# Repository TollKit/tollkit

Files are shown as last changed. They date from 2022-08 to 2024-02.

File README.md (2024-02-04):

# Sistema de Control de Acceso por COVID-19

             ![]() ![]() ![]() ![]() ![]() ![]() ![]() 

 <a width="400" href='https://postimages.org/' target='_blank'>Toll-Kit-github</a>

## Acerca del Proyecto

<a href='https://postimg.cc/GTtQ7r0N' target='_blank'>Whats-App-Image-2022-09-27-at-5-39-10-PM</a>

### Demo

https://drive.google.com/file/d/1ykN8uWTC-Xn_GCya3o3VD92Z7eDFktyV/view?usp=sharing

### Motivación

Buscamos inspirar a la próxima generación de científicxs e ingenierxs para que nos ayuden a explorar y aprender sobre tecnología. Compartimos la documentación completa de este dispositivo como una forma de aporte al desarrollo tecnológico a través de un proyecto divertido.

### Habilidades

Este proyecto tiene elementos de ensamblaje mecánico, utiliza componentes electrónicos y tiene un software que se encargará de ejecturar todo. Para completar con éxito este proyecto necesitará tener algo de experiencia en lo siguiente:

* **Diseño Mécanico:** Para diseñar el chasis junto a los compartimentos para almacenar cada módulo electrónico.

* **Electrónica:** Para implementar los diferentes módulos electrónicos que luego serán comunicados por MQTT a Flask.

* **Software:** Para el reconocimiento de mascarilla, detección del carnet de vacunación a través del QR y el desarrollo web.

La mayoría de requisitos son habilidades que puede aprender y adquirir con bastante rapidez viendo videos e investigando en Internet, y a lo largo del proyecto también tratamos de brindar información complementaria sobre algunas de ellas.

### Compromiso de tiempo esperado

Según nuestra experiencia, la construcción de este proyecto requiere no menos de 100 horas-persona y, según la familiaridad y el nivel de habilidad de los involucrados, podría ser mucho más. *Sin embargo, este proyecto principalmente pretende ser una herramienta de enseñanza y aprendizaje.* A lo largo de la documentación, tratamos de brindar información complementaria para aquellos que puedan ser nuevos en este tipo de proyecto.

### Roadmap de implementación

<a href='https://postimg.cc/MMtP3vhz' target='_blank'>roadmap-Toll-Kit</a>

Esta es una ruta para construir un TollKit y se divide en 6 etapas:

* **Etapa 1:** Empieza planificando el proyecto, teniendo en cuenta la disponibilidad de cada miembro, conocimientos y nuevas funcionalidades que quieran integrarle. Te recomendamos usar Trello!

* **Etapa 2:** Consigue todos los componentes electrónicos, filamento y elabora una arquitectura de software.
* **Etapa 3:** Empieza a probar el correcto funcionamiento de cada módulo electrónico por separado y descarga las librerías/frameworks necesarios.
* **Etapa 4:** Ensambla el diseño 3D y prueba los módulos de visión computarizada.
* **Etapa 5:** Monta los módulos electrónicos en el chasis e integralos con el servidor de Flask.
* **Etapa 6:** Después de que todo haya sido probado, calibrado y el software esté funcionando, ¡TollKit estará listo para su uso!

## Empieza aquí

* [Propósito](https://github.com/TollKit/tollkit/blob/master/proposito.md)

* [Electrónica](https://github.com/TollKit/tollkit/blob/master/electronic_device/docElectronica.md)
* Visión Computarizada
    * [Reconocimiento de Mascarilla](https://github.com/TollKit/tollkit/blob/master/web_app/server/flask_app/faceMask_detection/docDeteccionMascarilla.md)
    * [Detección del Carnet de Vacunación](https://github.com/TollKit/tollkit/blob/master/web_app/server/flask_app/QRcard_vacunation/docCarnetVacunacion.md)
* [Diseño 3D](https://github.com/TollKit/tollkit/blob/master/diseno_3D/docDiseno3D.md)
* [Desarrollo Web](https://github.com/TollKit/tollkit/blob/master/web_app/server/docDesarrolloWeb.md)

## Equipo

Estos fueron los creadores originales de este proyecto. Ahora, este repositorio open source está a la disposición de la comunidad tecnológica.

(https://postimg.cc/Bj5rPLWx)

<ul>
    <li>[Sebastian Nizama](https://www.linkedin.com/in/sebastian-nizama/) Sebastián Nizama (Electrónica) </li>
    <li>[Richard Elescano](https://www.linkedin.com/in/richard-elescano-reyna-9a6311224/) (Electrónica) </li>
    <li>[Marko Julca](https://www.linkedin.com/in/markostephano/) (Visión Computarizada & Diseño 3D) </li>
    <li>[Nicolas Silva](https://www.linkedin.com/in/nicolas-silva-matute/) (Electrónica & Diseño 3D) </li>
    <li>[Jhomar Astuyauri](https://www.linkedin.com/in/jhomar-astuyauri/) (Producto & Desarrollo de Software) </li>
</ul>

### Especial agradecimiento

Héctor Llamaccponca, Jean Kevin Inga y Paulo Quispe

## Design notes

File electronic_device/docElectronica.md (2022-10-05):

<h1>Desarrollo Electrónico</h1>

<h2>Componentes electrónicos</h2>

| Componente  | Descripción  | Imágen de referencia |
| :--- |:---| -----:|
| RFID módulo RC522 | El módulo RC522 es Lector-Grabador RFID 13.56MHz, posee comunicación SPI lo que permite trabajar fácilmente con la mayoría de microcontroladores. El rango de detección de tags RFID es de aprox. 5-7cm. Compatible con Arduino, Pic, Raspberry Pi y más. | <a href='https://postimg.cc/D8qqJHrj' target='_blank'>RFID</a> |
| Sensor ultrasónico HC-SR04  | Es un módulo electrónico que incorpora un par de transductores de ultrasonido que se utilizan de manera conjunta para determinar la distancia entre el sensor (módulo) y un objeto. El tiempo entre la transmisión y la recepción de la señal ultrasónica es usada para calcular la distancia.  |  <a href='https://postimg.cc/V0LczT44' target='_blank'>pngwing-com</a>|
| Sensor de temperatura infrorrojo Mlx90614 | Es un chip de silicio con una fina membrana micro mecanizada,diseñada para ser sensible a la radiación infrarroja emitida por un objeto a distancia. El sensor posee internamente una etapa de amplificación y digitalización(ADC) de la señal procedente de la membrana. La salida del sensor es lineal y se compensa de acuerdo a las variaciones de la temperatura ambiente. | <a href='https://postimg.cc/hfD9qrnj' target='_blank'>MLX90614</a> |
| Relé optoacoplador de 5 V | Este módulo relé sirve para conmutación de cargas de potencia. Los contactos de los relevadores están diseñados para conmutar cargas de hasta 10 A y 250VAC (30VDC), aunque se recomienda dejar un margen abajo de estos límites. El modulo permite manejar la bobina del relé y la señal de control puede provenir de cualquier circuito de control TTL como un microcontrolador o tarjeta Arduino salidas desde 3.3V-5V. |  <a href='https://postimg.cc/DWY6xpF1' target='_blank'>rele</a>|
| Bomba de agua AD20P | Es una bomba de agua DC sin escobillas con las características de larga vida, bajo ruido, chispa inversa, etc. Sin interferencias electromagnéticas. Voltaje de funcionamiento: CC 12 V. Corriente de funcionamiento: 400 mA. Cabezal máximo: 118.1 in. Caudal máximo: 240 L.  |  <a href='https://postimg.cc/7fYVyy6S' target='_blank'>pump</a>|
| ESP32 | Microcontrolador programable con ide arduino con un módulo WiFi integrado. Este será usado para la adquisición de las señales porvenientes de los sensores y del envío de datos mediante MQTT.  |  <a href='https://postimg.cc/dDX7BYmQ' target='_blank'>esp32</a>|

<h2>Implementación</h2>
<h3>Sensor de temperatura</h3>
Para esta aplicacion en especifico se uso este sensor para medir la temperatura corporal de las personas que desean ingresar a un espacio publico y que segun bajo las regulaciones del minsa ésta no puede exceder los 38°C.
<a href='https://postimg.cc/0r5stBmr' target='_blank'>MLX90614-with-ESP32-connection-diagram</a>

---------

Las conexiones serán las siguientes:

* VIN: +3.3V - +5.0V DC
* GND: 0V Tierra
* SCL: I2C clock
* SCL: I2C clock
* SDA: I2C data

---------
Para usar este sensor en el IDE de arduino debemos descargar la librería "Adafruit_MLX90614.h"

--------

Inicialmente llamamos a las librerias a utilizar , luego definimos las variables alarma y calibracion que seran las necesarias para indicar cuando la temperatura corporal de la persona sobrepase los 38°C, y la variable calibracion es necesaria para obtener una medicion mas exacta de nuestro sensor. Luego en el programa utilizamos el metodo de la clase mlx , el cual es :"mlx.readObjectTempC" el cual nos brindara la temperatura en °C, con este valor ajustaremos el valor de alarma para que envie un mensaje cuando se sobrepase el valor maximo. Finalmente enviaremos los datos via wifi utilizando el ESP32 con la libreria pubsubclient y mediante el protocolo MQTT.

<h3>Sensor ultrasónico</h3>
Para esta aplicación en específico se usó este sensor para realizar un dispensador en gel sin contacto, es decir, las personas en el ingreso al establecimiento solo deben acercar sus manos cierta distancia y con ayuda de este sensor se activará una bomba para dispensar alcohol en gel a fin de desinfectar las manos de la persona y cumplir con los protocolos sanitarios.
<a href='https://postimg.cc/8jJLqDrC' target='_blank'>1617136789-426-Tutorial-de-sensores-ultrasonicos-para-Arduino-ESP8266-y-ESP32</a>

---------

Las conexiones serán las siguientes:

* VCC (+5V DC)
* TRIG (Disparo del ultrasonido)
* ECHO (Recepción del ultrasonido)
* GND (Tierra: 0V)

---------
Para usar este sensor en el IDE de arduino no se utiliza librerías especiales para el sensor, solamente se utiliza la función "pulseIn" incluida en el IDE de Arduino para medir la longitud del pulso de eco que devuelve el sensor ultrasónico.

--------

Inicialmente se definen las variables en los pines y su estado de entrada o salida En este caso en particular se utilizó un relé como salida para activar la bomba que nos dispensara el alcohol en gel. Luego en el programa se realiza la ecuación del tiempo con la funcion Pulsein y se configura par aunque si la distancia es menor a 5 el relé se active y de lo contrario no lo haga Finalmente enviaremos los datos que indiquen si el relé se activó o no via wifi utilizando el ESP32 con la libreria "wifi.h" y la libreria "pubsubclient" para usar el protocolo MQTT.

<h3>Módulo RFID</h3>
Para esta aplicacion en especifico se uso este modulo para regular el ingreso en los establecimientos solo de personas autorizadas pertenecientes a la organizacion o invitados registrados.

<a href='https://postimg.cc/9RyyrBCq' target='_blank'>RFID-ESP32-Node-MCU-Steckplatine</a>

---------

Las conexiones serán las siguientes:

<a href='https://postimg.cc/ThqHsVgw' target='_blank'>nfc-osc-bb-g-Bdc-Dg8-Rq9</a>

---------
Para poder trabajar el Modulo en Arduino es necesario descargar su librería correspondiente, la que usaremos será la libreria : "MFRC522"

--------

Se tiene primero un código para leer el código de identificación de nuestros Tags, lo cual es necesario para realizar el control de acceso. Una vez obtenido los códigos de nuestros tags, ya podemos realizar el control de acceso indicando que códigos serán los que tendrán permitidos el ingreso, para ello primero se llama a las librerias a utilizar y luego de esto se crea objeto mfrc522 enviando pines de slave select y reset con esta linea: 
* MFRC522 mfrc522(SS_PIN, RST_PIN);
Posterior a esto se definen los usuarios que tendran permitido el ingreso, en este caso son los siguientes:
* byte Usuario1[4]= {0x82, 0x95, 0x40, 0x1C} ;    // UID de tarjeta leido en programa 1
* byte Usuario2[4]= {0xE0, 0xB2, 0x4E, 0xD3} ;    // UID de llavero leido en programa 1
Luego, con los metodos 
* mfrc522.PICC_IsNewCardPresent y mfrc522.PICC_ReadCardSerial
conoceremos si hay una tarjeta presente o si no se peuden obtener datos 
de la tarjeta
finalmente se imprime el mensaje de acceso concedido o acceso denegado
Todos los datos son enviados via WiFi por el ESP 32 con la libreria "WiFi.h"
y "pubsubclient" para hacer uso del protocolo MQTT

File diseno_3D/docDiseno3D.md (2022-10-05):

<h1>Desarrollo del Diseño 3D </h1>

Para el diseño 3D se utilizaron diferentes formas:

* Pirámide de 585 mm con base de 100 mm x 100 mm, de este se cortó 150 mm de altura con un cubo hueco.

* Para la superficie se utilizaron cuñas, que son formas de triangulo rectangulo que permiten hacer lineas sobresalientes.

* Para la salida donde se coloca la cámara, tendrems cilindros huecos y un circulo que genere una base que sobresalga. Se hicieron agujeros con los cilindros de 10 mm de diámetro.

* Para el RFID se utilizó un prisma rectangular con un hueco hecho usando un óvalo de 70 mm x 40 mm.

* Este prisma se inclinó para que sea de fácil acceso y se incrustó a TOLLKIT usando otro prisma de 60 mm x 40 mm.

* En la tapa se unieron dos prismas rectangulares, uno de 94 mm x 156 mm y otro de 90 mm x 50 mm. Estos se conectan con otro prisma de 30 mm x 94 mm.

* Finalmente, se realizaron huecos en la tapa usando formas vacias para que sea de fácil apertura.

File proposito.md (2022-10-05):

A día de hoy la pandemia ha cambiado en muchas formas la manera en cómo salimos y entramos a establecimientos (Centros comerciales, restaurantes, universidades, etc.) por restricciones de COVID-19. A partir de esto han surgido nuevas responsabilidades como el del personal de seguridad encargado de verificar si cuentas con Mascarilla, Carnet de Vacunación con 3 dosis, Temperatura menor a 38.5, Carnet Universitario, verter alcohol en gel para la desinfección de tus manos y finalmente permitirte el pase al establecimiento.
<p>Identificamos las siguientes 3 problemáticas:</p>
<ul>
    <li>Realizar este tipo de tareas repetitivas termina siendo estresante para el personal de seguridad generando tensiones musculares, inflamación, problemas con los nervios, etc.</li>
    <li>Al ser el personal de seguridad un intermediario entre todas las personas del exterior y el establecimiento, existe un mayor riesgo de contagio debido a que si el personal de seguridad se contagia de forma asintomática, podría inconscientemente contagiar a cada persona que va ingresando al establecimiento siendo esto perjudicial.</li>
    <li>Es cierto que en muchos lugares el personal de seguridad está atento a que cada persona cumpla con las consideraciones mínimas para ingresar a un establecimiento, sin embargo, también es cierto que entre tantas personas, el error humano puede estar presente. El personal de seguridad no siempre verifica que se tenga un carnet de vacunación real y muchas veces vierte cualquier cantidad de gel.</li>
</ul>
Por esa razón decidimos crear TollKit, una herramienta que busca complementar la labor del personal de seguridad haciendo todas las tareas repetitivas de verificación de Mascarilla, Carnet de Vacunación con 3 dosis, Temperatura menor a 38.5, Carnet Universitario y dispensar alcohol en gel. Proporcionando además un Dashboard con todas las métricas necesarias para tener controladas las restricciones por COVID19. De esta forma, el personal podrá hacerse cargo de otras responsabilidades que impliquen un esfuerzo humano necesario.</p>

<center>
    <a href='https://postimages.org/' target='_blank'>seguridad1</a>
    <a href='https://postimages.org/' target='_blank'>seguridad2</a>
    <a href='https://postimages.org/' target='_blank'>seguridad3</a>
</center>

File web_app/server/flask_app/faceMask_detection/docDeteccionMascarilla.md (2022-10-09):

<h1>Desarrollo del Reconocimiento de Mascarilla </h1>

## Repositorio de referencia

https://github.com/balajisrinivas/Face-Mask-Detection

## Repositorio de referencia

Video de guía para uso del código

## Topología de la CNN

Para el entrenamiento del modelo se aplica transfer learning con el modelo base MobileNetV2. 
MobileNetV2 es una arquitectura de red neuronal convolucional que busca funcionar bien en dispositivos móviles. Se basa en una estructura residual invertida donde las conexiones residuales se encuentran entre las capas de cuello de botella. La capa de expansión intermedia utiliza circunvoluciones ligeras en profundidad para filtrar entidades como fuente de no linealidad. En conjunto, la arquitectura de MobileNetV2 contiene la capa inicial de convolución completa con 32 filtros, seguida de 19 capas de cuello de botella residuales.

## Requerimientos

* Python 3.6 (única versión de Python 3 que permite la instalación de tensorflow 1)

* Numpy 1.18.2 (importante)

* Scipy 1.4.1 (importante)

* Keras 

* Tensorflow 1.7.0

## Solución de errores

ARCHIVO:
En el archivo detect_mask_video.py
Revisar línea 76 y 77:

### Path a los archivos .model y .prototxt

Revisar línea la implementación del algoritmo de detección en la línea 112.
Explicación: La idea era que el script se cierre cada vez que detectaba una mascarilla, la variable cont (contador) se emplea para aproximar que la persona lleve la mascarilla puesta al menos 2seg (cont=20), ahí el script entrega la variable “Tiene Mascarilla” y de caso contrario, si el contador de frames sin mascarilla es 110, el script se cierra y se entrega la variable “No tiene Mascarilla”

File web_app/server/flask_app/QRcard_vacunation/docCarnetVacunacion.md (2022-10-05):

<h1>Desarrollo de la Detección de Carnet de Vacunación a través del QR  </h1>

# Codigo-QR

## Acerca de la automatización para el acceso

Para un mayor alcance en la data de las personas en relación a las dosis de la vacuna contra la covid 19, el minsa es la institución la cual
posee la información que se usara para la obtención de los datos de los usuarios que iran pasando atravez de Tollkit, los datos que obtendremos son el nombre, la cantidad de dosis y la edad, esto con el fin de ir registrando y corroborando posteriormente atravez de flask, si de acuerdo con la edad que tenga el usuario cumpla con el mínimo de dosis suministradas.
La interacción física con Tollkit en el proceso de automatización se dara mediante el lector de código qr que la página del minsa posee, mediante Seleium el proceso de automatización para el control de dosis se podrá llevar acabo.

## API documentación:

* [Selenium](https://github.com/SeleniumHQ/selenium)
<h3>Automatización de la página del Minsa</h3>
<p>Para el proceso de automatización de la pagina:</p>
<ul>
  <li>A través de Selenium y el lenguaje de programación de Python, comanzaremos controlando mediante un WebDriver el navegador que usaremos, por ejemplo si quisieramos controlar desde el navegador Chrome será:
https://chromedriver.chromium.org/downloads, para saber la versión que se debera descargar, nos dirigimos a la sección-Ayuda-del navegador posteriormente se le dara a -Información de Google Chrome-y se podra observar la versión que se este usando, para luego pasar a la descarga del controlador del navegador.</li>
<li>Para la codificación identificaremos la ruta en donde guardamos el controlador del navegador: C:/Program Files (x86)/chromedriver.exe, definimos como path a esta ruta, posteriormente usaremos la ruta de la página:     website='https://carnetvacunacion.minsa.gob.pe/#/verify-qr/enable, usaremos webdriver.Chrome para poder abrir la página que desea usar, creamos los elementos nombres, dosis y edad, usaremos el atributo xpath, usaremos el método que nos
devolvera una lista de palabras claves que queremos que nos retorne, en este caso el nombre del usuario, la palabra que muestre la cantidad de dosis y la edad, el atributo usado sera el find_element.' 
</li>
 </ul>

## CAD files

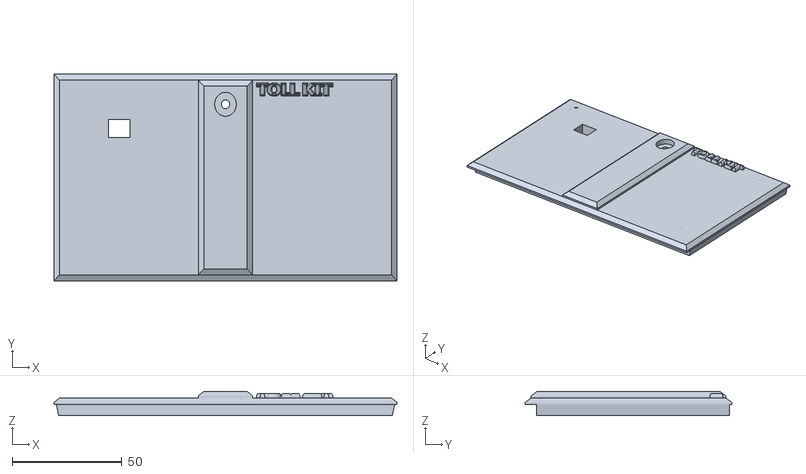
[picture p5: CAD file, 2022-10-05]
diseno_3D/Tapa.stl
156.0 x 94.0 x 11.0

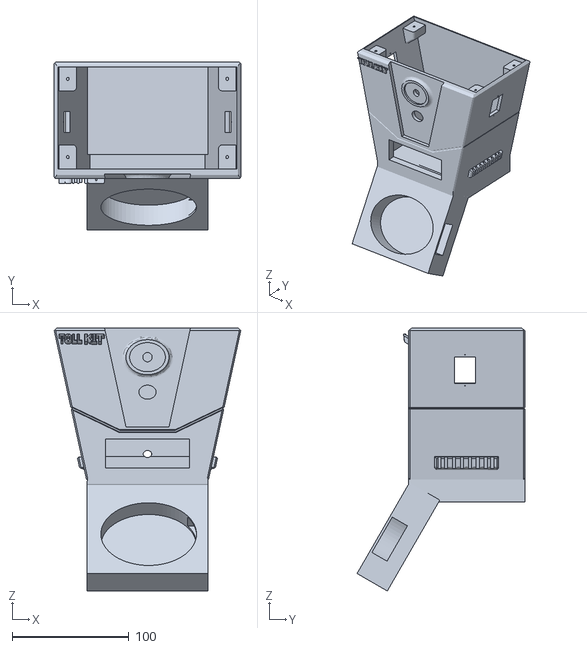
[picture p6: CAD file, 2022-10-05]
diseno_3D/ChasisPrincipal.stl
160.0 x 144.0 x 225.5

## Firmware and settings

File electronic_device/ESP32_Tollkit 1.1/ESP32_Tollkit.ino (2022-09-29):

// CREDENCIALES 
 char* ssid = "Nizama iPhone 11";
 const char* contrasena = "sebastian54321";
 //char* ssid = "JUL_NIZ";
 //const char* contrasena = "FIEE20182";

int trig = 25;
int echo = 26;
int relay = 4;
long tiempo;
long distancia;
int estado_actual = 0;

// sensor temperatura
#include <Adafruit_MLX90614.h> 
#include<Wire.h>
#include <WiFi.h>
#include<PubSubClient.h>
#include <LiquidCrystal_I2C.h>
LiquidCrystal_I2C lcd(0x27, 16, 2);
#include <SPI.h>      // incluye libreria bus SPI
#include <MFRC522.h>      // incluye libreria especifica para MFRC522
#define SS_PIN 5
#define RST_PIN 2
const char* servidor_mqtt= "172.20.10.5"; //mosquitto
int puerto = 1883;
 
WiFiClient espClient;
PubSubClient client(espClient);
MFRC522 mfrc522(SS_PIN, RST_PIN); // crea objeto mfrc522 enviando pines de slave select y reset
//sensor de temperatura
Adafruit_MLX90614 mlx = Adafruit_MLX90614(); 
int alarma = 33;         // valor de temperatura de alarma
int calibracion = 5;     // factor de calibracion 


byte LecturaUID[4];         // crea array para almacenar el UID leido
byte Usuario1[4]= {0x82, 0x95, 0x40, 0x1C} ;    // UID de tarjeta leido en programa 1
byte Usuario2[4]= {0xE0, 0xB2, 0x4E, 0xD3} ;    // UID de llavero leido en programa 1

void setup_wifi(){
  delay(10);
  Serial.println();
  Serial.print("Connecting to ");
  Serial.println(ssid);
  WiFi.begin(ssid,contrasena);
  //Conexion a wifi
  while(WiFi.status()!=WL_CONNECTED){
  delay(300);
  Serial.print(".");
  }
}

void reconnect(){
  while(!client.connected()){
    Serial.println("Intentando conexion MQTT con parametros configurados...");
    if(client.connect("ESP32")){
      Serial.println("Conectado");
    }else{
      Serial.print("Falla, Estado:");
      Serial.print(client.state());
      Serial.println("Intentando conexion nuevamente en 2s...");
      delay(2000);
    }
  }
}
void setup() {
  //sensor ultrasonico
  pinMode(trig, OUTPUT);
  pinMode(echo, INPUT);
  pinMode(relay, OUTPUT);
  digitalWrite(relay, HIGH);
  digitalWrite(trig, LOW);//Inicializamos el pin con 0
  
  Serial.begin(115000); 
  setup_wifi();
  client.setServer (servidor_mqtt, puerto);
  mlx.begin(); // sensor de temperatura
  SPI.begin();        // inicializa bus SPI
  mfrc522.PCD_Init();     // inicializa modulo lector
  Serial.println("Listo");    // Muestra texto Listo

  lcd.init();
  lcd.backlight();
  lcd.clear();
  lcd.setCursor(5,0);
  lcd.print("TOLLKIT"); // Mensaje a desplegar
  delay(3000); // espera 3 segundos con el mensaje estatico
}

void loop() {
  if(!client.connected()) //para que se reconecte//
  reconnect();
 
  digitalWrite(trig, HIGH);
  delayMicroseconds(10);
  digitalWrite(trig, LOW);
  tiempo = pulseIn(echo, HIGH);
  distancia = tiempo / 58.2;
  if (estado_actual == 0){
    lcd.clear();
    lcd.setCursor(0,0);
    lcd.print("1/5 Reconocim."); // Mensaje a desplegar
    lcd.setCursor(0,1);
    lcd.print("de mascarilla"); // Mensaje a desplegar
    delay(10000);
    lcd.clear();
    lcd.setCursor(0,0);
    lcd.print("2/5 Carnet de"); // Mensaje a desplegar
    lcd.setCursor(0,1);
    lcd.print("vacunacion (QR)"); // Mensaje a desplegar
    delay(5000);
    estado_actual = 1;
    }
  if (estado_actual == 1){
    lcd.clear();
    lcd.setCursor(0,0);
    lcd.print("3/5 Medicion de"); // Mensaje a desplegar
    lcd.setCursor(0,1);
    lcd.print("temperatura"); // Mensaje a desplegar
    }
  if (estado_actual == 2){
    lcd.clear();
    lcd.setCursor(0,0);
    lcd.print("4/5 Carnet"); // Mensaje a desplegar
    lcd.setCursor(0,1);
    lcd.print("universitario"); // Mensaje a desplegar
    }
  if (estado_actual == 3){
    lcd.clear();
    lcd.setCursor(0,0);
    lcd.print("5/5 Desinfeccion"); // Mensaje a desplegar
    lcd.setCursor(0,1);
    lcd.print("de manos"); // Mensaje a desplegar
    }
  
  if (distancia <= 8 && estado_actual==3){
    Serial.print(distancia);      //Enviamos serialmente el valor de la distancia
    Serial.print("cm ");
    Serial.println("GEL");
    client.publish("gel", "OK"); //ENVIO MQTT GEL
    digitalWrite(relay, LOW);
    delay(4000);
    client.publish("alcohol", "True"); //ENVIO MQTT TEMPERATURA
    digitalWrite(relay, HIGH);
    estado_actual = 0;
    lcd.clear();
    lcd.setCursor(0,0);
    lcd.print("Gel: "); // Mensaje a desplegar
    lcd.setCursor(0,1);
    lcd.print("OK"); // Mensaje a desplegar
    delay(3000); // espera 3 segundos con el mensaje estatico
  }
  else{
    Serial.println("ESTATICO");
    //digitalWrite(relay, LOW);
    Serial.print(distancia);      //Enviamos serialmente el valor de la distancia
    Serial.print("cm ");
  }
  
  double h=mlx.readObjectTempC()+calibracion; //lectura del sensor de temperatura
  String ST=String(h,2);
  //if(!client.connected()) //para que se reconecte//
  //reconnect();
  
  //SENSOR TEMPERATURA
  client.loop();
  if(h>35 && estado_actual==1){
    client.publish("temp", ST.c_str()); //ENVIO MQTT TEMPERATURA
    estado_actual = 2;
    lcd.clear();
    lcd.setCursor(0,0) ;
    lcd.print("Temperatura:"); // Mensaje 2 a desplegar
    lcd.setCursor(0,1) ;
    lcd.print(ST); // Mensaje 2 a desplegar
    delay(2000);
    }
  //lcd.setCursor(0,1) ;
  //lcd.print(ST); // Mensaje 2 a desplegar
  Serial.println(ST);
  delay(2000);

  
  if ( ! mfrc522.PICC_IsNewCardPresent())   // si no hay una tarjeta presente
    return;           // retorna al loop esperando por una tarjeta
  
  if ( ! mfrc522.PICC_ReadCardSerial())     // si no puede obtener datos de la tarjeta
    return;           // retorna al loop esperando por otra tarjeta

  if(estado_actual==2){
    
    Serial.print("TOLLKIT:");       // muestra texto UID:
    for (byte i = 0; i < mfrc522.uid.size; i++) { // bucle recorre de a un byte por vez el UID
          
          LecturaUID[i]=mfrc522.uid.uidByte[i];     // almacena en array el byte del UID leido      
          }
          
          Serial.print("\t");         // imprime un espacio de tabulacion             
                    
          if(comparaUID(LecturaUID, Usuario1)){    // llama a funcion comparaUID con Usuario1
            client.loop();
            client.publish("rfid", "Estudiante UNI"); //id
            delay(2000);
            Serial.println("Bienvenido Jhomar Astuyauri");
            estado_actual = 3;
            lcd.clear();
            lcd.setCursor(0,0) ;
            lcd.print("Grupo:"); // Mensaje 2 a desplegar
            lcd.setCursor(0,1) ;
            lcd.print("Estudiante UNI"); // Mensaje 2 a desplegar
            delay(2000);
            } // si retorna verdadero muestra texto bienvenida
          
          else if(comparaUID(LecturaUID, Usuario2)){ // llama a funcion comparaUID con Usuario2
            client.loop();
            client.publish("rfid", "EXTRENO"); //id
            delay(2000);
            Serial.println("ACCESO DENEGADO");
            estado_actual = 3;
            lcd.clear();
            lcd.setCursor(0,0) ;
            lcd.print("Grupo:"); // Mensaje 2 a desplegar
            lcd.setCursor(0,1) ;
            lcd.print("Externo"); // Mensaje 2 a desplegar
            delay(2000);
            } // si retorna verdadero muestra texto bienvenida
          
          else{           // si retorna falso
            client.loop();
            client.publish("rfid", "MUESTRE CARNET"); //id
             delay(2000);
            Serial.println("MUESTRE CARNET"); }   // muestra texto equivalente a acceso denegado          
                  
          mfrc522.PICC_HaltA();     // detiene comunicacion con tarjeta
  }
  
  delay(3000);

}

boolean comparaUID(byte lectura[],byte usuario[]) // funcion comparaUID
{
  for (byte i=0; i < mfrc522.uid.size; i++){    // bucle recorre de a un byte por vez el UID
  if(lectura[i] != usuario[i])        // si byte de UID leido es distinto a usuario
    return(false);          // retorna falso
  }
  return(true);           // si los 4 bytes coinciden retorna verdadero
}

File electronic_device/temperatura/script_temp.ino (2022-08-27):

// CREDENCIALES 
// const char* ssid = "Redmi";
// const char* contrasena = "123456789";




#include<WiFi.h>
#include<PubSubClient.h>
#include "credenciales.h"
#include <Adafruit_MLX90614.h> 
#include<Wire.h>
const char* servidor_mqtt= "192.168.43.114"; //mosquitto
int puerto = 1883;

WiFiClient espClient;
PubSubClient client(espClient);
Adafruit_MLX90614 mlx = Adafruit_MLX90614();
int alarma = 33;         // valor de temperatura de alarma
int calibracion = 5;     // factor de calibracion 
void setup_wifi(){
  delay(10);
  WiFi.begin(ssid,contrasena);
  while(WiFi.status()!=WL_CONNECTED){
  delay(300);
  }
}
void reconnect(){
  while(!client.connected()){
    Serial.println("Intentando conexion MQTT con parametros configurados...");
    if(client.connect("ESP32")){
      Serial.println("Conectado");
    }else{
      Serial.print("Falla, Estado:");
      Serial.print(client.state());
      Serial.println("Intentando conexion nuevamente en 2s...");
      delay(2000);
    }
  }
}

void setup() {
  Serial.begin(9600);
  setup_wifi();
  client.setServer (servidor_mqtt, puerto);
  mlx.begin(); 
}

void loop() {
  double h=mlx.readObjectTempC()+calibracion;
if(!client.connected()) //para que se reconecte//
  reconnect();
  client.loop();
  client.publish("temp", String(h).c_str());
  delay(2000);
  }

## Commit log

2022-08-13 métodos de los modelos
2022-08-13 cambio de nombres app
2022-09-09 landing first part
2022-09-09 login & landing
2022-09-24 Regrese lo que habia
2022-09-24 code Tollkit ESP32
2022-09-26 versiones de cada libreria
2022-09-26 creé la carpeta webapp
2022-09-26 implementé la carpeta para la detección de mascarillas
2022-09-27 integración de los 4 pasos
2022-09-27 topic de alcohol en gel
2022-09-27 automatización pyautogui para la detección del carnet de vacunación
2022-09-29 agregue la fecha a la tabla
2022-10-05 feat: distribución de readmes
